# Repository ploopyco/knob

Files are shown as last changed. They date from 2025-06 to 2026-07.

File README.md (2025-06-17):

# The Ploopy Knob

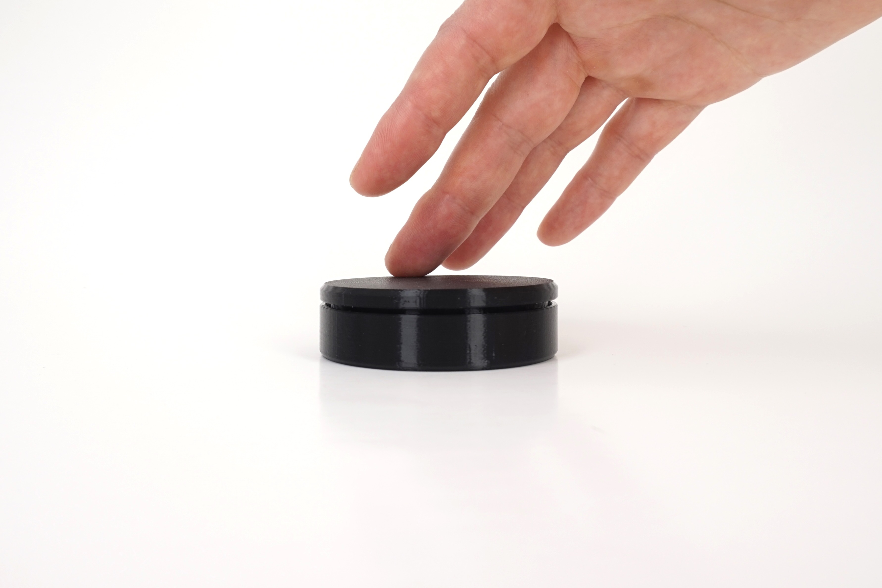
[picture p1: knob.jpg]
The Ploopy Knob


By some stroke of luck, you've made your way here. The Ploopy Knob. Your life will never be the same.

This repository contains all of the design and production files necessary to make a Ploopy Knob. We've also included some kick-ass documentation on how to get it made, assemble it, and program it [which you can find here](https://ploopyco.github.io/knob/).

What are you waiting for? Your new life awaits.

## QMK?!

Knobs bought from the [Ploopy store](https://ploopy.co/product-category/knob) come with QMK preloaded. [Check out the documentation](https://ploopyco.github.io/knob/) for instructions on how to load new firmware onto your device. (It's super easy!)

The firmware file that ships with all Knobs is included in this repository as well, as `ploopyco_knob_slow.uf2`. We also have a few other precompiled firmwares, so try which one works best for you.

## Under what license is this released?

As per QMK's licensing requirements, the firmware for the Ploopy Knob is released under GPLv3. Hardware design files, including electronics and mechanical files, are released under OHL CERN v2-S. Check the respective directories for full license text.

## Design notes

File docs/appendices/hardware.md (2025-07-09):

# Appendix C: Hardware

## Buying hardware from us

Getting all of the hardware on your own can be tricky because the parts you select may not fit perfectly. [That's why we sell fully-assembled Knobs](https://ploopy.co/product-category/knob/). Here's why that's great for you:

- Everything is guaranteed to fit together perfectly
- Everything is guaranteed to work as intended
- You'll end up saving money - probably quite a bit of money - by not spending on extra parts

Your call. You'll sort it out.

## Getting your own hardware

This guide was a bit light on detail in the other sections, and that's because the hardware has to conform to many specifications. They'll all be listed here.

First, a complete list of all the hardware you'll need:

- \#2 1/4" screws, x2
- 6mm diameter x 2mm thick magnet, x2
- 6705ZZ bearing
- 4x friction pads

We'll be going over all of them in detail. There will be mentions of *critical specifications*; if you're going to be sourcing your own parts, **you must get parts that conform to the critical specifications**. If you go off-menu, the parts will not fit the way that we intended when we designed the Knob. That might mean that your Knob **doesn't work**.

Let's get cracking.

### Screws

Here are the critical specifications:

- \#2
- 1/4" length

### Magnets

Here are the critical specifications:

- 6mm diameter
- 2mm thickness

### 6705ZZ Roller Bearing

Here are the critical specifications:

- 6705ZZ bearing
- 25mm inner diameter
- 32mm outer diameter
- 4mm thickness

### Friction pads

Here are the critical specifications:

- Circular shape
- Up to 3/4" diameter
- Up to 1/8" thickness
- Non-slip

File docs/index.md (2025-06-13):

# Home

So, you want to build a Ploopy Knob, eh? Or, maybe you want to replace some broken parts. Maybe you want to reprogram it. Or maybe you just want to know how it all works. No matter the motivation, this is the place to learn.

**Sourced the parts and itching to get it built?** --> Get started by going to the [assembly instructions](assembly-instructions.md).

**Looking to purchase your own Knob?** --> [Check out the Ploopy store](https://ploopy.co/product-category/knob).

**Building a Ploopy Knob from scratch?** --> Get started by going to [Appendix A: Printed circuit boards](appendices/pcbs.md).

---

*Copyright (C) 2025 Ploopy Corporation. Permission is granted to copy, distribute and/or modify this document under the terms of the GNU Free Documentation License, Version 1.3 or any later version published by the Free Software Foundation; with no Invariant Sections, no Front-Cover Texts, and no Back-Cover Texts. A copy of the license is included in the section entitled "GNU Free Documentation License".*

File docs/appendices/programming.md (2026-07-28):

# Appendix D: QMK Firmware Programming

## Working with QMK

Ploopy devices are fairly easy to program and reprogram, thanks to the excellent work by all of the developers and maintainers of the [QMK firmware suite](https://github.com/qmk/qmk_firmware).

## Before you begin

If you have never used QMK before, go through [all of the steps in the QMK guide to set up your environment](https://docs.qmk.fm/#/newbs_getting_started).

QMK was built for keyboards, so you'll see lots of references to code that looks like the following:

`-kb <keyboard>`

Whenever you see that, use the following syntax:

`-kb ploopyco/knob`

and you'll be fine.

## Building the Ploopy device firmware

Using QMK MSYS or your compilation toolchain of choice, compile the firmware with the following command:

`qmk compile -kb ploopyco/knob/rev1_001 -km default`

For more details on building QMK firmware in general, see the [QMK firmware guide](https://docs.qmk.fm/#/newbs_building_firmware).

## Putting the Ploopy device into bootloader mode

Putting the Ploopy device into bootloader mode is very simple and straightforward.

1. Unplug it from your computer.
2. Open it by removing the Top (it's attached via friction and requires some force to pull up and off).
3. Look for a pair of vias (gold-plated holes) on the board ([here's a photo](https://ploopy.co/wp-content/uploads/2025/06/knob-vias.jpg)).
4. Get a paper clip (non-insulated, i.e. no plastic shit covering it) or a pair of tweezers, or some wire. Whatever you've got on hand that's metal.
5. Stick the paper clip or tweezers into the holes. You're trying to form an electrical connection between the two holes.
6. While you've got the two vias connected with your metal bridge, plug the Ploopy device into your computer.
7. The computer should recognise that a mass storage device was just plugged in. Once this is done, you should be able to drag and drop files onto the Ploopy device, as if the board was a USB drive. Feel free to remove the tweezers or paperclip at this point.

And that's it. While plugged in this way, the Ploopy device will accept new firmware.

If you want to upload a new firmware file (a ".uf2" file, like "ploopy_knob_v42069" or something), just drag it into the folder, and it'll automatically install on the Ploopy device and restart itself.

Whenever you want to put new firmware onto the Ploopy device, go through these steps again.

**TIP**: If your firmware is in some kind of strange state and uploading new firmware isn't fixing it, try uploading [a flash nuke](https://learn.adafruit.com/getting-started-with-raspberry-pi-pico-circuitpython/circuitpython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) to the knob before flashing the new firmware. It wipes the memory of the knob completely clean, which can help clear a few types of errors.

## And that's it!

Happy customizing!

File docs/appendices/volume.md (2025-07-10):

# Appendix F: Volume Knob Patch

A pre-compiled UF2 file to use the Knob as a volume controller is included in the firmwares directory of the Github repository.

If you'd like to build your own, here's a patch you can apply to the code to get you started:

    diff --git a/keyboards/ploopyco/knob/config.h b/keyboards/ploopyco/knob/config.h
    index 9b7d9f5c1a..92d97584cc 100644
    --- a/keyboards/ploopyco/knob/config.h
    +++ b/keyboards/ploopyco/knob/config.h
    @@ -16,7 +16,7 @@

     #pragma once

    -#define POINTING_DEVICE_HIRES_SCROLL_ENABLE 0
    +// #define POINTING_DEVICE_HIRES_SCROLL_ENABLE 0
     #define POINTING_DEVICE_AS5600_ENABLE true

     #define I2C_DRIVER I2CD1
    diff --git a/keyboards/ploopyco/ploopyco.c b/keyboards/ploopyco/ploopyco.c
    index 72fad42aba..24428a73c3 100644
    --- a/keyboards/ploopyco/ploopyco.c
    +++ b/keyboards/ploopyco/ploopyco.c
    @@ -180,23 +180,12 @@ report_mouse_t pointing_device_task_kb(report_mouse_t mouse_report) {
             delta += 4096;
         }

    -    if (detected_host_os() == OS_WINDOWS || detected_host_os() == OS_LINUX) {
    -        // Establish a deadzone to prevent spurious inputs
    -        if (delta > POINTING_DEVICE_AS5600_DEADZONE || delta < -POINTING_DEVICE_AS5600_DEADZONE) {
    -            current_position = ra;
    -            mouse_report.v = delta / POINTING_DEVICE_AS5600_SPEED_DIV;
    -        }
    -    } else {
    -        // Certain operating systems, like MacOS, don't play well with the
    -        // high-res scrolling implementation. For more details, see:
    -        // https://github.com/qmk/qmk_firmware/issues/17585#issuecomment-2325248167
    -        if (delta >= POINTING_DEVICE_AS5600_TICK_COUNT) {
    -            current_position = ra;
    -            mouse_report.v = 1;
    -        } else if (delta <= -POINTING_DEVICE_AS5600_TICK_COUNT) {
    -            current_position = ra;
    -            mouse_report.v = -1;
    -        }
    +    if (delta >= POINTING_DEVICE_AS5600_TICK_COUNT) {
    +        current_position = ra;
    +        tap_code(KC_VOLD);
    +    } else if (delta <= -POINTING_DEVICE_AS5600_TICK_COUNT) {
    +        current_position = ra;
    +        tap_code(KC_VOLU);
         }
     #endif

Happy coding!

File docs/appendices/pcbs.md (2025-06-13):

# Appendix A: Printed circuit boards

## Buying boards from us
Getting the Ploopy boards made can be complex, and expensive, especially if you only need one set. [That's why we sell fully-assembled Knobs](https://ploopy.co/product-category/knob/). Here's why that's great for you:

- You get a PCB with all components soldered
- The firmware is already programmed on the microcontroller, so you won't have to program it
- It'll cost a hell of a lot less than if you do a production run of PCBs just for yourself
- You won't have to order components and wait while they come in
- We guarantee that it works

Just something to consider. You're smart. You'll figure it out.

## Making your own boards

Want to make your own Ploopy Knob boards? Great! Less work for us. Seriously, though, only choose this option if you know what you're doing. You don't want to embarrass yourself, do you?

### Step 1: Order the PCBs from a PCB production company

Here are the most important configurations you'll need to communicate to the company:

- 4 layers
- FR-4, TG 150-160 (basically, whatever the cheapest option is)
- 1.6mm thickness
- 6/6mil track/spacing distance
- 0.3mm minimum hole size
- ENIG surface finish, but you can go with HASL if you don't care about lead poisoning
- 1oz copper thickness for both outer and inner layers
- Choose whatever colours you want for solder mask and silkscreen; we like green solder mask and white silkscreen

If something is missing from here, it's not really important.

At some point, you'll have to upload design files to the production company. Use the [electronics source files](https://github.com/ploopyco/knob/tree/master/hardware/electronics) to generate manufacturing files (you'll have to convert them from their native Altium format if you're using some other platform). That should contain everything you need to get the boards made. If the production company rejects this package, however, you'll need to address the issue yourself.

### Step 2: Order the electronics components

All of the components are described in the schematics of the PCBs. Ordering the components is left as an exercise for the reader.

A complete list of all of the components can be found in the electrical design files.

### Step 3: Get the necessary tools

- PCB
- All of the electronics components
- A hot air rework tool
- Solder paste
- A printout of the schematics

### Step 4: Solder the components to the boards

Once you've got the PCBs and all of the components, print out the schematics. Use the schematics to match the reference designators on the PCBs to the reference designators on the schematics, and then get to soldering.

If you've never soldered surface mount components before, or want a refresher on how to solder, we recommend [this video on using an iron to solder surface mount components](https://www.youtube.com/watch?v=3NN7UGWYmBY), and [this video on using a hot-air soldering station](https://www.youtube.com/watch?v=c_Qt5CtUlqY).

### Step 5: All done!

Congrats, you finished assembling the electronics! Pat yourself on the back.

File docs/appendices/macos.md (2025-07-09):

# Appendix E: MacOS Compatibility

Currently, MacOS does its own smoothing to implement high-resolution scrolling. As a result of that, HID-based high-res scrolling (such as the kind implemented in QMK) doesn't work well. More discussion on this topic [can be seen here](https://github.com/qmk/qmk_firmware/issues/17585).

The current firmware implements notched scrolling for MacOS, which then smoothes the motion. However, it isn't as precise as it is in the Windows and Linux implementations. For this reason, we designate that high-resolution scrolling is not officially supported by the Knob.

## Workaround #1: discrete-scroll

A possible workaround is to utilise [the open-source library "discrete-scroll"](https://github.com/emreyolcu/discrete-scroll). This disables the smooth scrolling on MacOS.[^1]

After that, a new version of the firmware will have to be built. Begin by modifying the QMK file "keyboards/ploopyco/ploopyco.c". Change the following lines:

    #ifdef POINTING_DEVICE_AS5600_ENABLE
        // Get AS5600 rawangle
        uint16_t ra = get_rawangle();
        int16_t delta = (int16_t)(ra - current_position);

        // Wrap into [-2048, 2047] to get shortest direction
        if (delta > 2048) {
            delta -= 4096;
        } else if (delta < -2048) {
            delta += 4096;
        }

        if (d_os == OS_WINDOWS || d_os == OS_LINUX) {
            // Establish a deadzone to prevent spurious inputs
            if (delta > POINTING_DEVICE_AS5600_DEADZONE || delta < -POINTING_DEVICE_AS5600_DEADZONE) {
                current_position = ra;
                mouse_report.v = delta / POINTING_DEVICE_AS5600_SPEED_DIV;
            }
        } else {
            // Certain operating systems, like MacOS, don't play well with the
            // high-res scrolling implementation. For more details, see:
            // https://github.com/qmk/qmk_firmware/issues/17585#issuecomment-2325248167
            if (delta >= POINTING_DEVICE_AS5600_TICK_COUNT) {
                current_position = ra;
                mouse_report.v = 1;
            } else if (delta <= -POINTING_DEVICE_AS5600_TICK_COUNT) {
                current_position = ra;
                mouse_report.v = -1;
            }
        }
    #endif

to this:

    #ifdef POINTING_DEVICE_AS5600_ENABLE
        // Get AS5600 rawangle
        uint16_t ra = get_rawangle();
        int16_t delta = (int16_t)(ra - current_position);

        // Wrap into [-2048, 2047] to get shortest direction
        if (delta > 2048) {
            delta -= 4096;
        } else if (delta < -2048) {
            delta += 4096;
        }

        // Establish a deadzone to prevent spurious inputs
        if (delta > POINTING_DEVICE_AS5600_DEADZONE || delta < -POINTING_DEVICE_AS5600_DEADZONE) {
            current_position = ra;
            mouse_report.v = delta / POINTING_DEVICE_AS5600_SPEED_DIV;
        }
    #endif

After recompiling and reflashing (see [Appendix D: QMK Firmware Programming](programming.md) for more details), you should get smooth scrolling, just the same as on Windows or Linux.

## Workaround #2: BetterMouse

Another workaround is using BetterMouse. It requires downloading paid software, and is verified as working.

[A full write-up on how to do this is available here](https://www.reddit.com/r/ploopy/comments/1lv1i6m/got_the_knob_found_a_macos_workaround/).[^2]

[^1]: Thanks to [asyncmeow](https://fedi.rrr.sh/@pearl) for her contributions to this fix.
[^2]: Thanks to [u/SilentStormer](https://www.reddit.com/user/SilentStormer/) for his contributions to this fix.

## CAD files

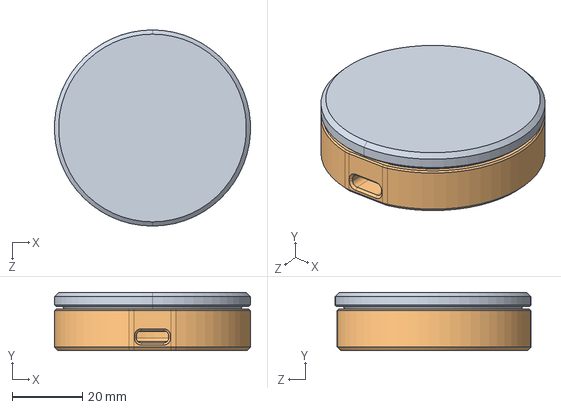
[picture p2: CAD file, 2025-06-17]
hardware/mechanicals/knob.STEP
56.0 x 16.6 x 56.0 mm

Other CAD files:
hardware/mechanicals/knob.3mf
hardware/mechanicals/knob.STL

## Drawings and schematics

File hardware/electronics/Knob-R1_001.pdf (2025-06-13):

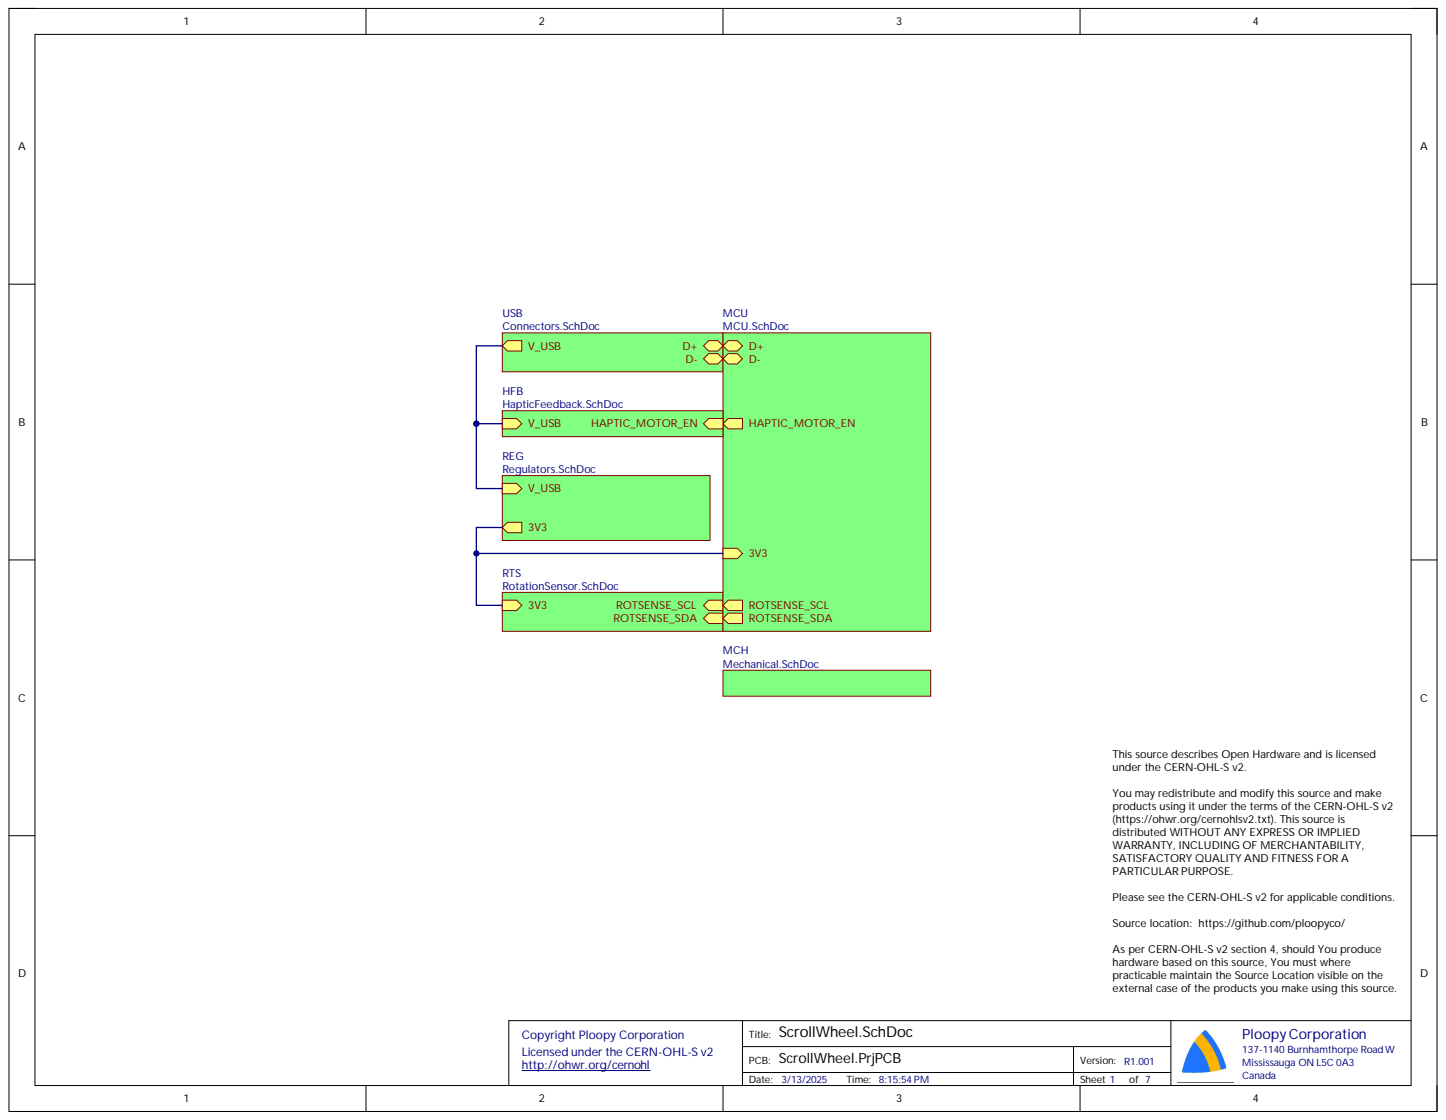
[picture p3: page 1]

This source describes Open Hardware and is licensed
under the CERN-OHL-S v2.

You may redistribute and modify this source and make
products using it under the terms of the CERN-OHL-S v2
(https://ohwr.org/cernohlsv2.txt). This source is
distributed WITHOUT ANY EXPRESS OR IMPLIED
WARRANTY, INCLUDING OF MERCHANTABILITY,
SATISFACTORY QUALITY AND FITNESS FOR A
PARTICULAR PURPOSE.

Please see the CERN-OHL-S v2 for applicable conditions.

Source location: https://github.com/ploopyco/

As per CERN-OHL-S v2 section 4, should You produce
hardware based on this source, You must where
practicable maintain the Source Location visible on the
external case of the products you make using this source.

Copyright Ploopy Corporation
Licensed under the CERN-OHL-S v2
http://ohwr.org/cernohl

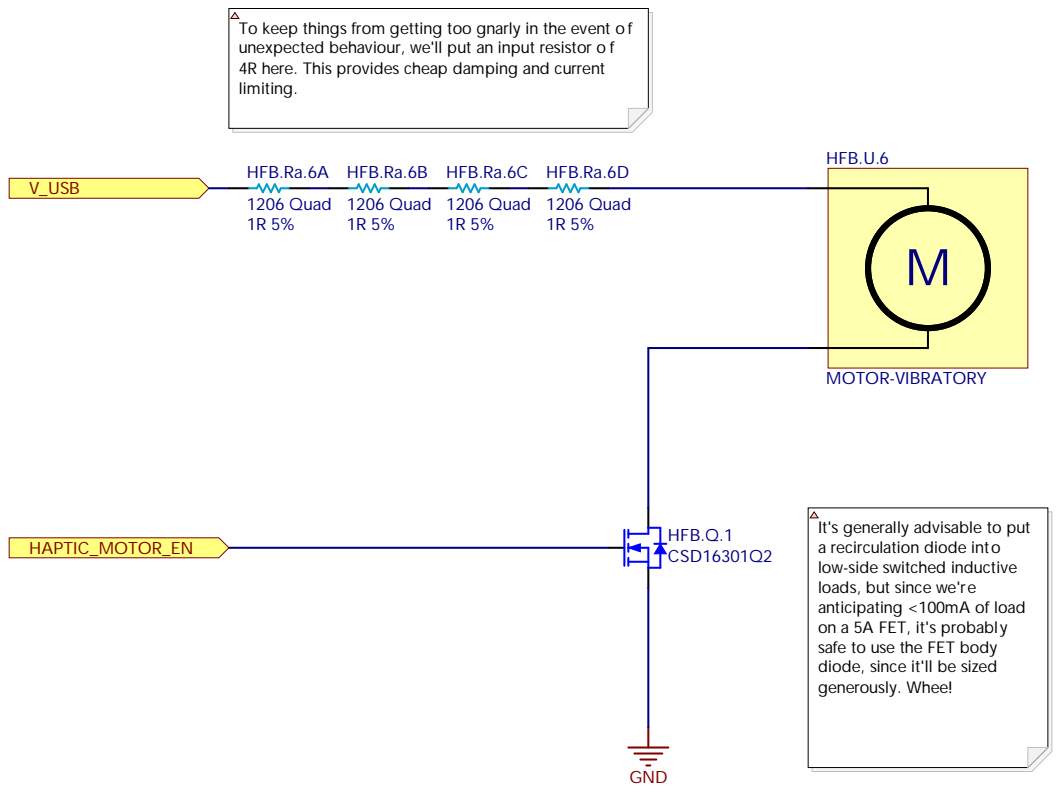
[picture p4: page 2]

To keep things from getting too gnarly in the event of
unexpected behaviour, we'll put an input resistor of
4R here. This provides cheap damping and current
limiting.

It's generally advisable to put
a recirculation diode into
low-side switched inductive
loads, but since we're
anticipating <100mA of load
on a 5A FET, it's probably
safe to use the FET body
diode, since it'll be sized
generously. Whee!

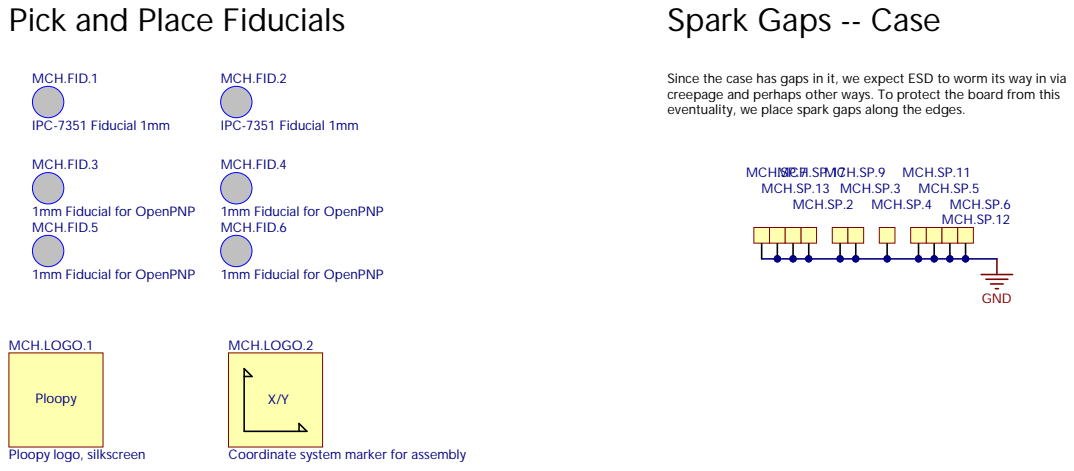
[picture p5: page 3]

Pick and Place Fiducials

Spark Gaps -- Case MCH.SP.7MCH.SP.2 MCH.SP.9 MCH.SP.3 MCH.SP.4 MCH.SP.1

Since the case has gap
creepage and perhap
eventuality, we place s

s other ways. To protect the board from this
park gap

pect ESD to worm its way in via

Coordinate system marker for assem

Cop
Licensed under the CE
http

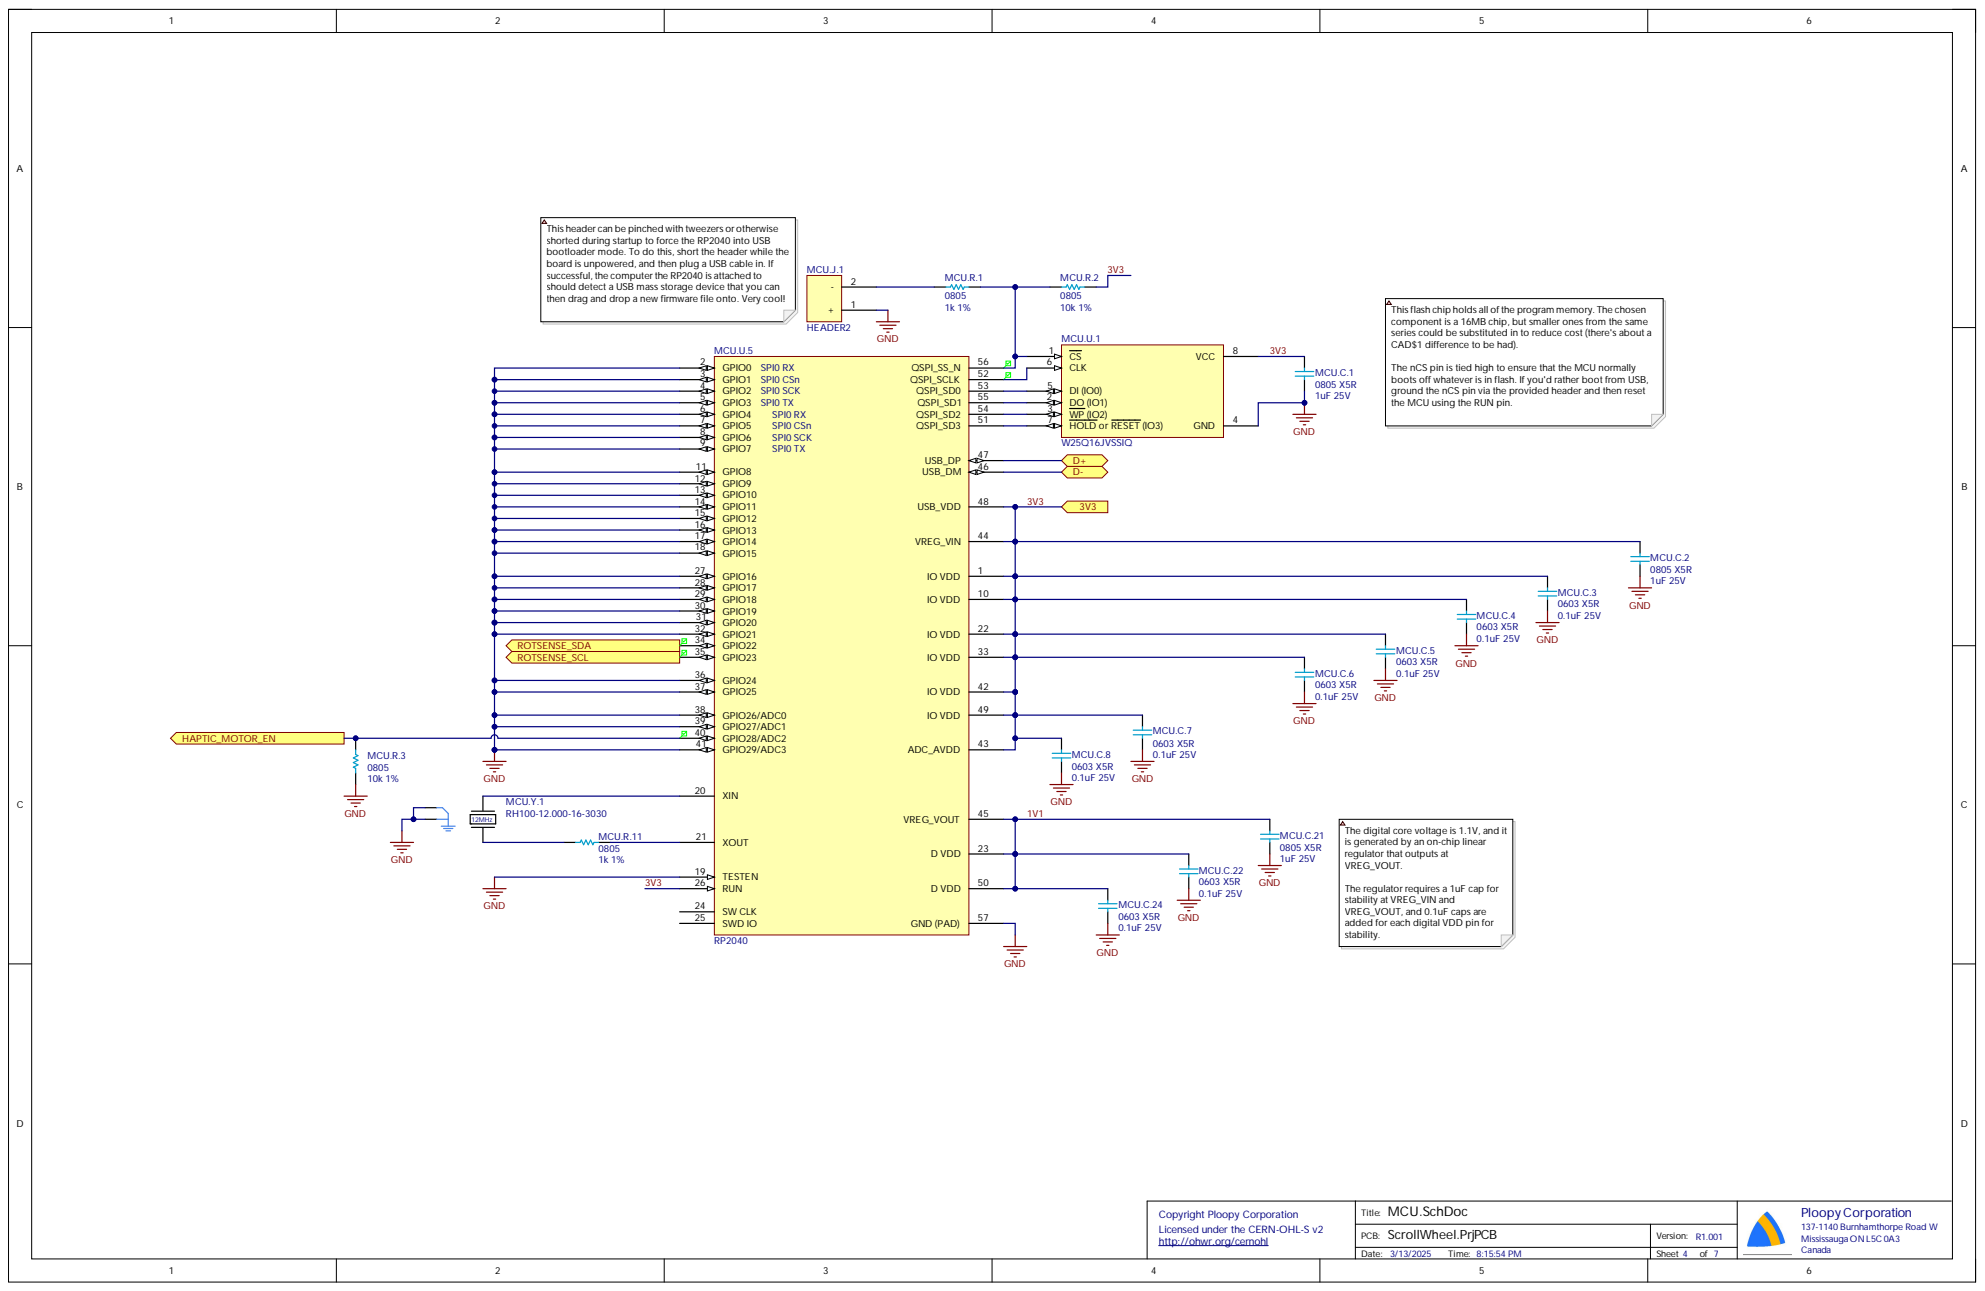
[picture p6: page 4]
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

PC B : Scr ollWh e el.P rj PC B | V e rsion : R 1 . 001

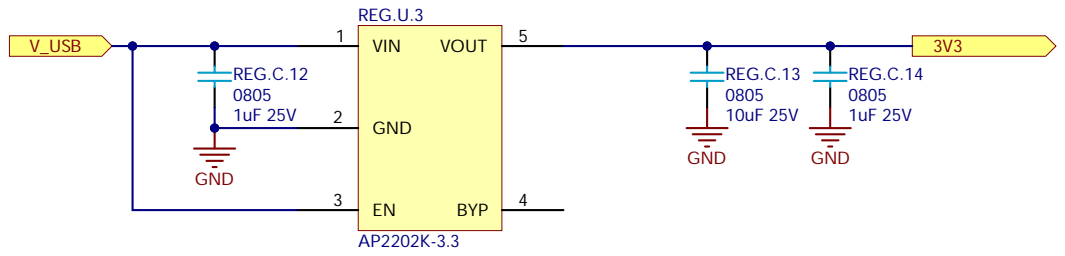
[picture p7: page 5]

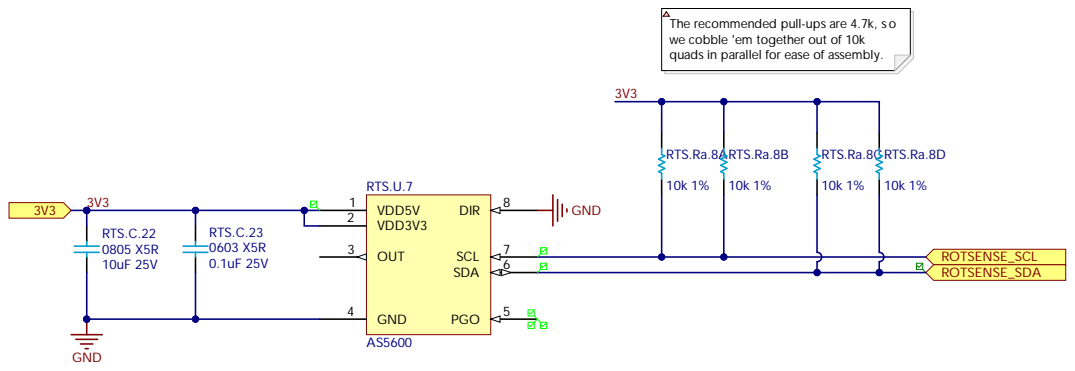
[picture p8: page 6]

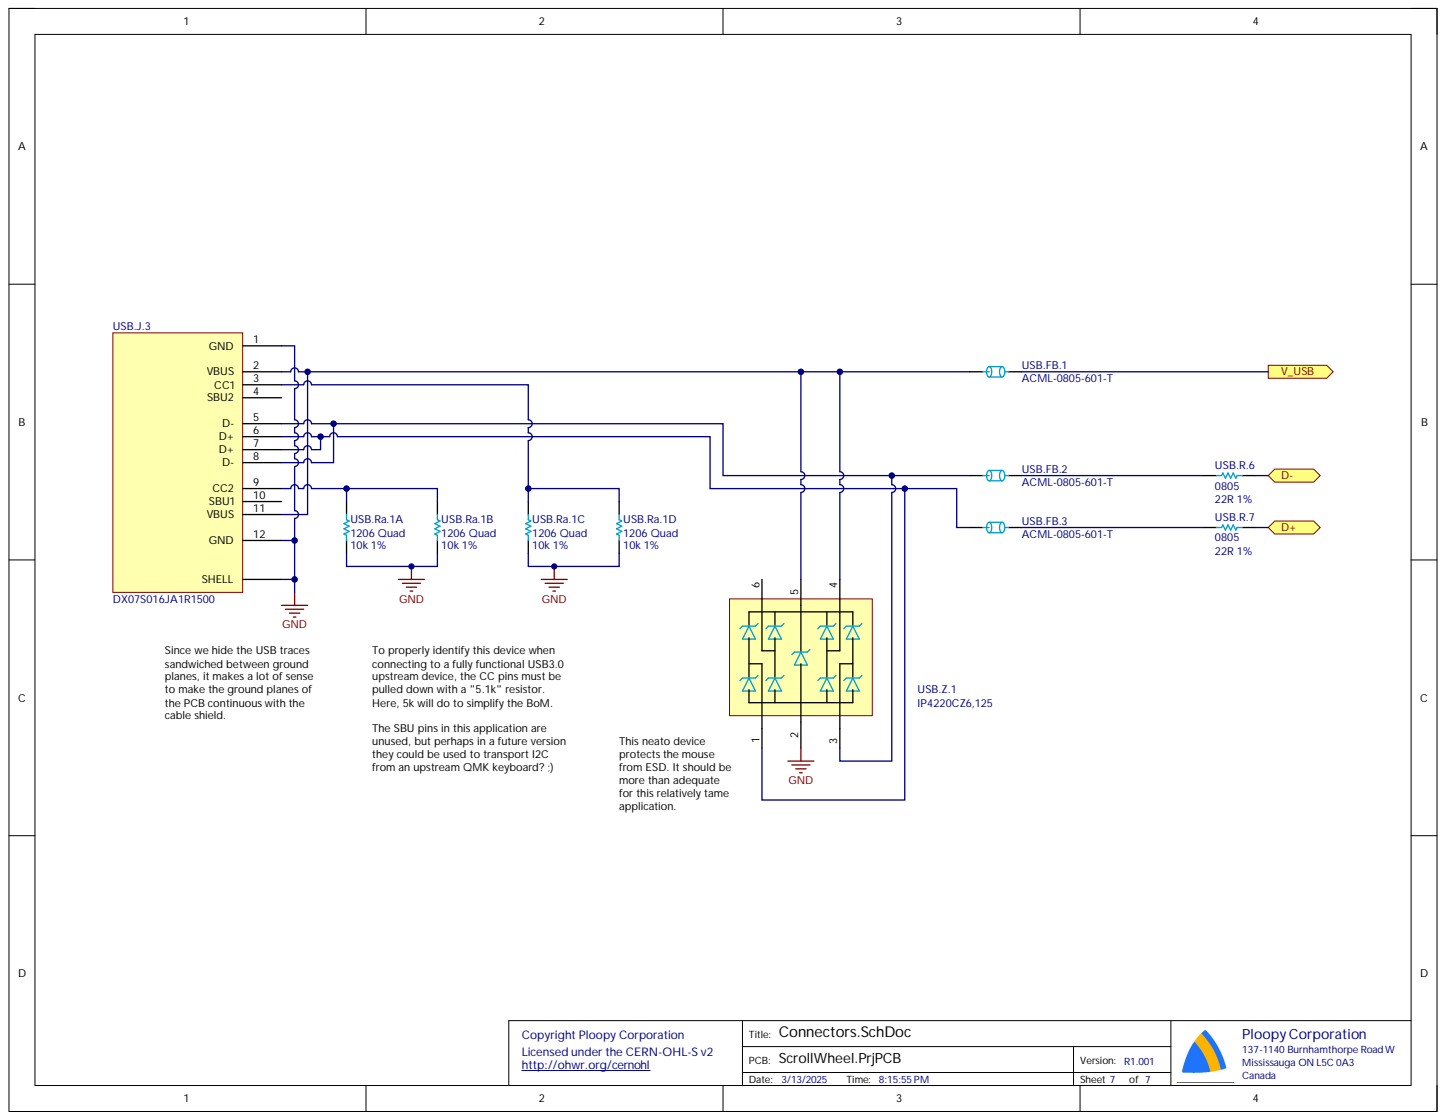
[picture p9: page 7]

Since we hide the USB traces sandwiched between ground planes, it makes a lot of sense

To properly identify this device when
connecting to a fully functional USB3.0
pulled down with a "5.1k" resistor.
Here, 5k will do to sim

to make the ground planes of
the PC
cable shield

The SB
unused, but perhap
they could be used to trans
from an up

U pins in this ap

This neato device protects the mouse

from ESD. It should be more than adequate

for this relatively tame

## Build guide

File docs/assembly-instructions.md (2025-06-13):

# Ploopy Knob Assembly Instructions

## Main Instructions

In this section, you'll go over how to build a Ploopy Knob. This assumes you've sourced the parts yourself following the designs in this repository.

Here's how these instructions are structured*:

- 💡 Comments with a lightbulb are good information to know.
- ➡️ Comments with an arrow are commands. Execute them when you encounter them.
- ✅ Comments with a checkmark are verification steps. Check what they tell you to check, and if it's all good, move on.
- 📷 Comments with a camera are references to photos. Check the corresponding image for guidance.

Most steps have photos, so if you need some additional visual help, consult the images.

*\* Thanks to [schneems](https://github.com/schneems) for his [great suggestions on how to write documentation](https://github.com/ploopyco/headphones/issues/37).*

### Step 1

- ➡️ Get a #1 Phillips head screwdriver (or similar; you're looking for a small-ish screwdriver here).
- 💡 A pair of needle-nose pliers and a pair of tweezers are optional, but they'll make future steps easier.

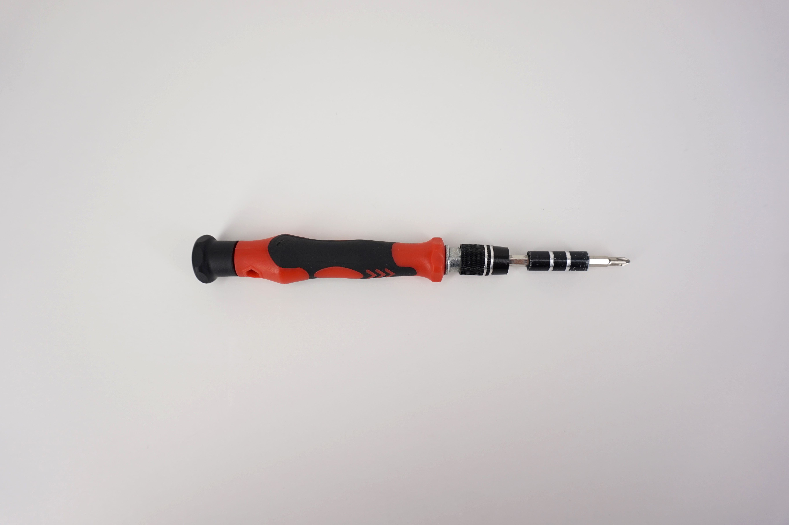
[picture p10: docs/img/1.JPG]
|  |
|:--:|
| *Figure 1: Necessary tools* |

### Step 2

- ➡️ Grab the plastic knob base, the PCB, and two #1 Phillips head plastic screws.
- ➡️ Place the PCB in the base of the knob. Make sure to align the USB port with the slot for it in the base. 📷 *See Figure 2.2.*
- ➡️ Screw in the two screws. 📷 *See Figure 2.3.*

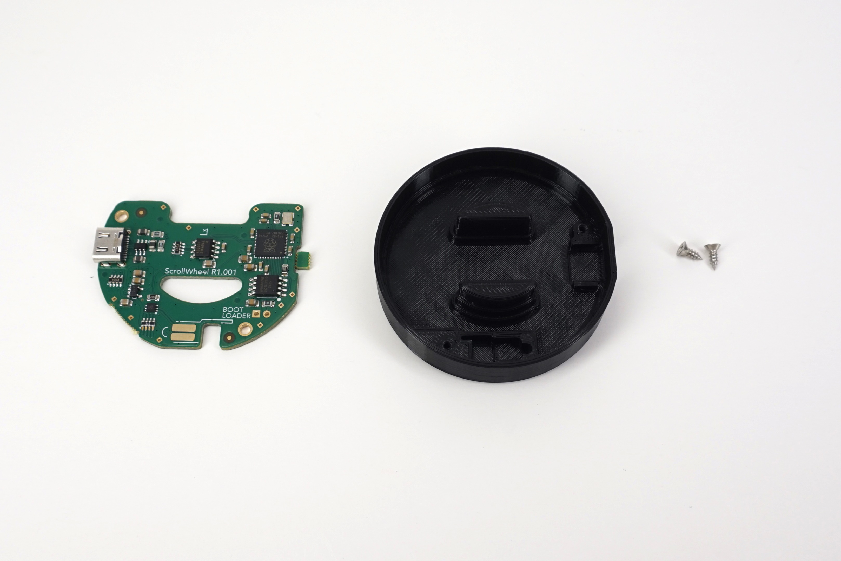
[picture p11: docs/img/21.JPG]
|  |
|:--:|
| *Figure 2.1: Parts needed for Step 2* |

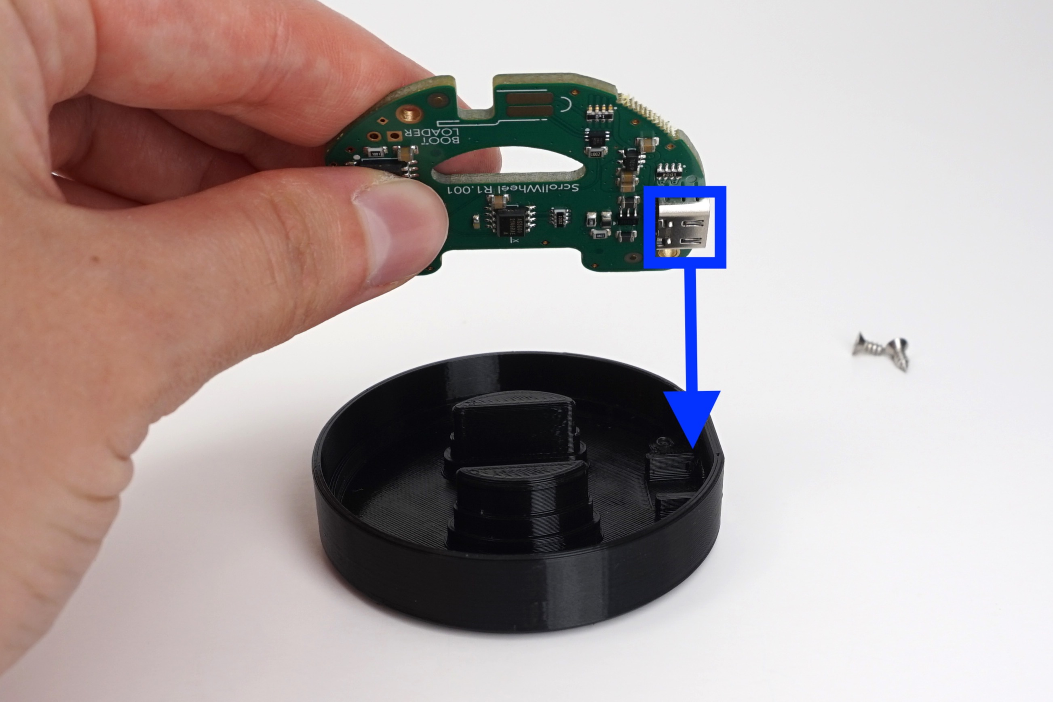
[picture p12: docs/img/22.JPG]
|  |
|:--:|
| *Figure 2.2: Align the USB port on the PCB with the slot in the base* |

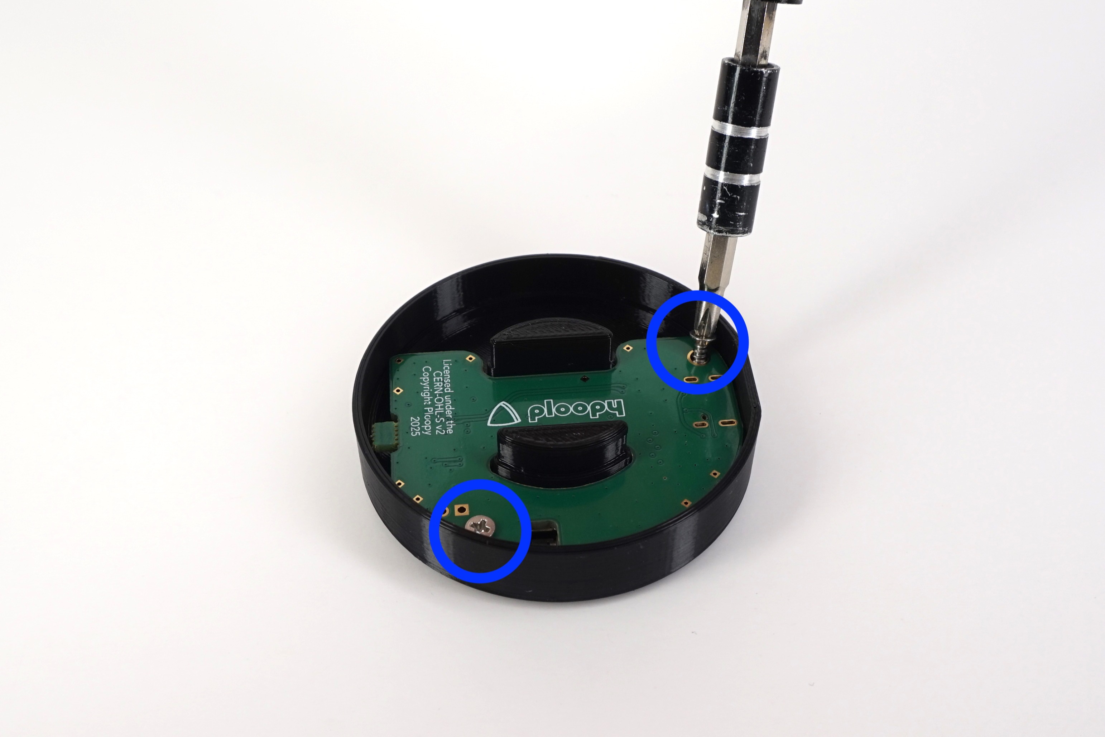
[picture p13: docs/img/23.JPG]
|  |
|:--:|
| *Figure 2.3: Attach the PCB with two screws* |

### Step 3

- ➡️ Grab the top half of the knob and two magnets.
- ➡️ Take ONE of the two magnets and insert it into one of the slots. A little force is required to press this first magnet into its slot. 📷 *See Figure 3.2.*
- 💡 Do not insert magnet #2 until explicitly told to do so.
- 💡 Magnet #1 when inserted should be free to rattle around a bit inside its slot before magnet #2 is installed. This is how you know magnet #1 is fully pressed in.
- 💡 The orientation of both magnets needs to be verified before inserting magnet #2. When both magnets are inserted correctly, they'll attract each other, not repel each other.
- ➡️ Without inserting it, place magnet #2 on the outside of the cylinder, closest to the empty slot. It should stick to the cylinder due to the magnetic attraction. 📷 *See Figure 3.3.*
- 💡 Now, magnet #2 is oriented correctly. It just needs to be slipped into the slot.
- ➡️ Without rotating magnet #2, slip it into its slot and press it in.
- 💡 When both magnets are fully seated, you should hear a click as the two magnet snap together from inside their respective slots.

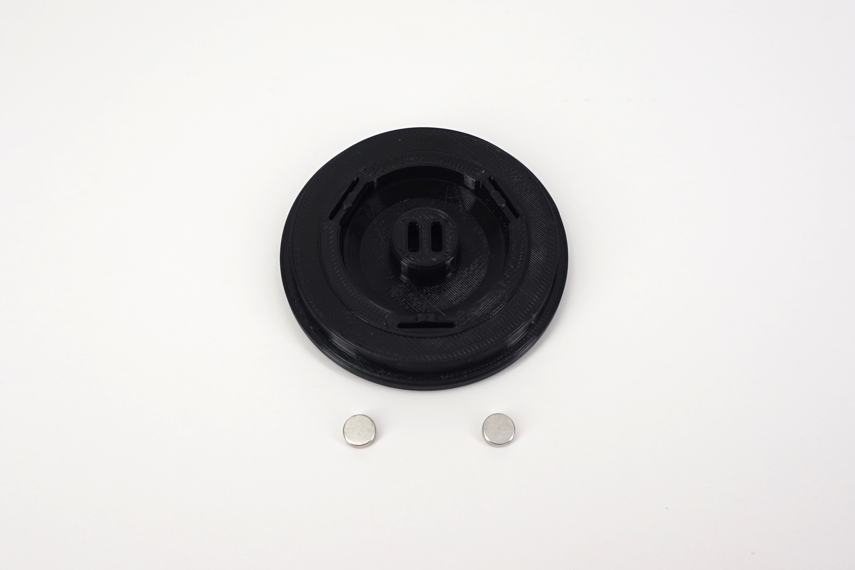
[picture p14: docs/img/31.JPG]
|  |
|:--:|
| *Figure 3.1: Parts needed for Step 3* |

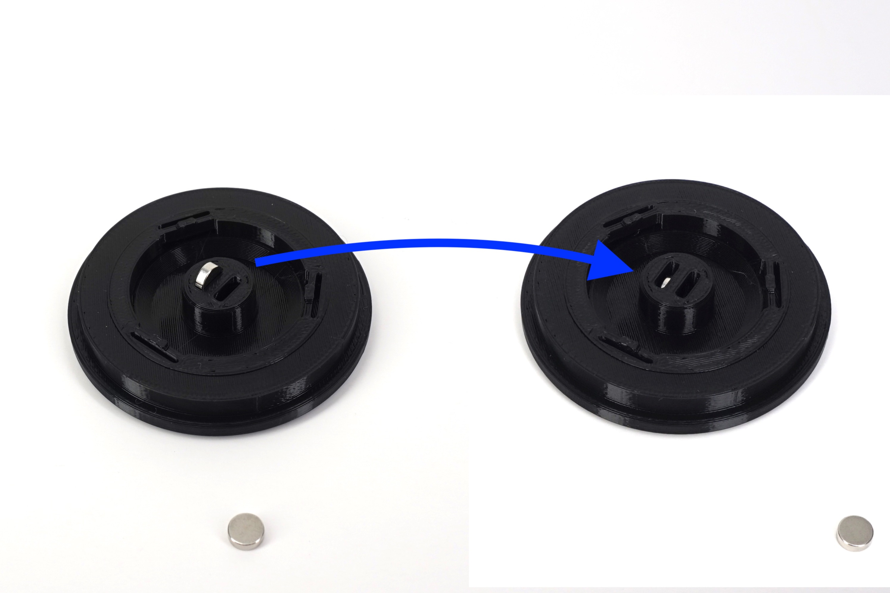
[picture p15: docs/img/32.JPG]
|  |
|:--:|
| *Figure 3.2: Insert magnet #1 into the slot* |

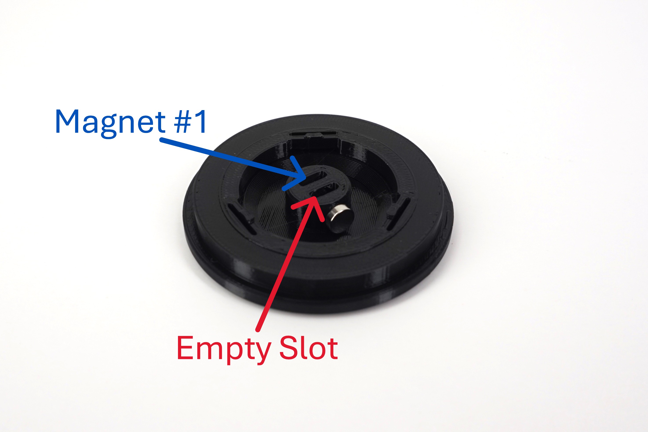
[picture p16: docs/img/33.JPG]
|  |
|:--:|
| *Figure 3.3: Align magnet #2 with the first* |

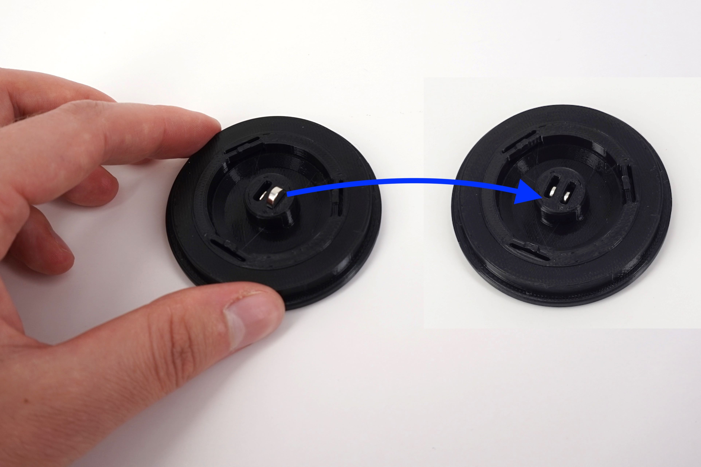
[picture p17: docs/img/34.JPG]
|  |
|:--:|
| *Figure 3.4: Press magnet #2 into its slot* |

### Step 4

- ➡️ Gently press the bearing into the top half of the knob.
- 💡 Press with your thumbs all around the circumference of the bearing to make sure it's seated all the way into the slot.

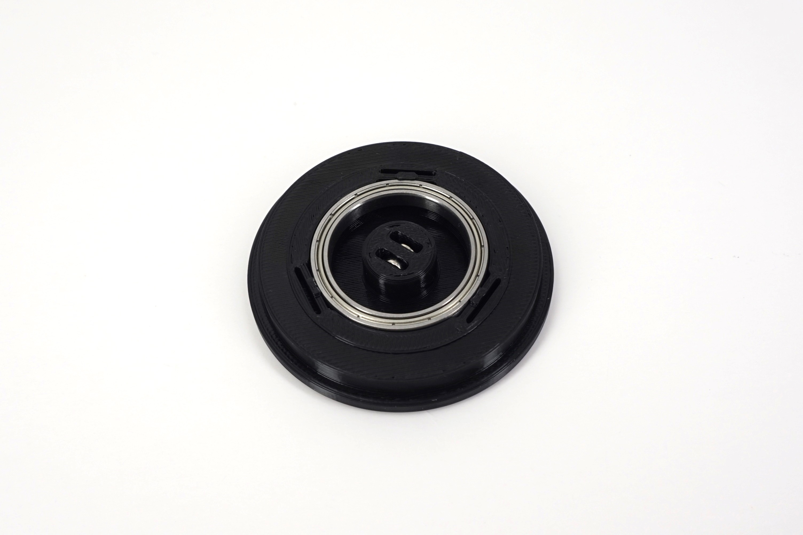
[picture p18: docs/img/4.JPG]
|  |
|:--:|
| *Figure 4: Press the bearing into the top half of the knob* |

### Step 5

- ➡️ Take the top half of the knob, place it above the bottom half, making sure the two circles line up. Press the top half into the bottom half.
- ➡️ You're done! Plug it in and take it for a spin!

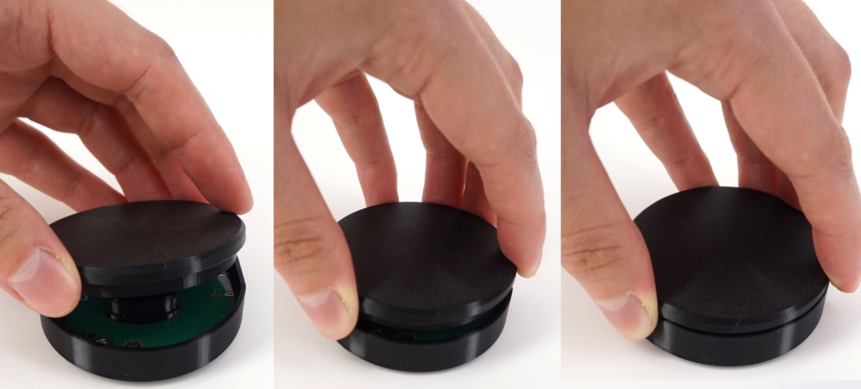
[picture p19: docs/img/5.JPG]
|  |
|:--:|
| *Figure 5: Press the knob halves together* |

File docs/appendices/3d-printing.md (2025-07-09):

# Appendix B: 3D printed parts

## Buying 3D-printed parts from us
Not everyone has access to a 3D-printer. [That's why we sell fully-assembled Knobs](https://ploopy.co/product-category/knob/). Here's why that's great for you:

- You get all of the 3D-printed parts, guaranteed free of manufacturing defects
- You won't waste time spending hours tweaking settings
- We guarantee it will fit together *perfectly*

Consider it. You're a smartie. You'll get there.

## Printing your own parts

So, you have a printer and want to print your own parts? Great! We don't have specific instructions, since every printer setup is different. All of the STLs are available, and if you need to make tweaks, you can alter the design files.

Here are the settings we use when we print parts. **Note that these settings have only been tested on the Prusa i3 MK2.5S and MK3S.** If you have another printer, you may need to tweak these settings.

- PLA. The geometry of many of the parts is quite complex; trying to use other materials may not result in success.
- 0.30mm layer height. You can go finer than this if you want, but we haven't tested that. Going coarser is not going to work; first, it's going to feel rough on your hand, and second, it won't accurately capture the necessary detail.
- No support material is necessary. If your slicer is showing support material, you didn't orient the parts correctly.
- Orient the pieces so that flat sides are on the build plate.
- We like gyroid for infill pattern, but anything is probably good. Cubic, rectilinear, whatever.
- We use 0.4mm nozzles. We haven't tested other nozzle sizes.

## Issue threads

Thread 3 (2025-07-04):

Parts list "motor-vibratory" is incorrect and unidentifiable

harakan2, 2025-07-04:
The parts list has no part number for the "MOTOR-VIBRATORY" item, and is linked to Octopart for a totally unrelated item (some sort of high-power AC motor controller?):
https://octopart.com/5250-mlp3-allen+bradley-19947531

The description just says "A sort of bargain basement miscellaneous kind of vibration motor that can be found on AliExpress", with no link, part number, or specification for dimensions/voltage/etc. and a search on AliExpress for "vibratory motor" does not show anything that resembles the 3D model in the CAD package.

fkpwolf, 2025-07-27:
looks like this one?

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

search with "Apple DC2V-3V Vibration Motor"

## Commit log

2025-06-13 added electrical files
    [Chip_Passives.PcbLib, Chip_Passives.SchLib, Connectors.SchDoc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]
2025-06-13 added schematic
2025-06-17 added mechanicals
    [knob.3mf, knob.STEP, knob.STL]
